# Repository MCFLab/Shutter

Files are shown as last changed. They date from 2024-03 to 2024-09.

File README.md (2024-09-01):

# Welcome to the Shutter Project!

The **Shutter Project** is an open-source development of a low-cost, general purpose shutter system based on ubiquitous actuators (servo motors or solenoids) that are connected to an Arduino-based controller. Several shutters can be controlled by one controller, reducing system cost. The state of the shutters can be controlled via a display built into the controller, by serial commands via USB, or by electrical control lines. The use of a microcontroller makes the shutter controller adaptable – only control options that are used need to be included, and the design accommodates a selection of display and actuator options. We provide designs for all required components, including 3D print files for the actuator holders and cases, software for the Arduino, libraries for serial communication (C and python), and example graphical user interfaces for testing. 

*Reference:*  Mathias S. Fischer and Martin C. Fischer. Cost-effective, open-source light shutters with Arduino control. [HardwareX 19, e00548 (2024)](https://doi.org/10.1016/j.ohx.2024.e00548)

## Rotary Solenoids
Since publication of the HardwareX paper, we have also tested the controller with rotary solenoids, which perform quite a bit better then servos. We added a document in the Docs folder describing the operation with rotary solenoids in a bit more detail. Also, for questions and discussion refer to the [this topic](https://forum.microlist.org/t/cost-effective-open-source-light-shutters-with-arduino-control/) in the [Builders/Tools Category](https://forum.microlist.org/c/builders-tools/21) of the [µForum](https://forum.microlist.org/).

## Contributing
I welcome your contributions with [pull-requests](https://github.com/MCFLab/Shutter/pulls) and [issues suggesting further improvement](https://github.com/MCFLab/Shutter/issues)!

## License
This work is licensed under the
[CERN Open Hardware Licence Version 2 - Weakly Reciprocal License](https://cern-ohl.web.cern.ch/).

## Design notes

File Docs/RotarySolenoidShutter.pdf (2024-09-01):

# Operation with a rotary solenoid

This document supplements the open-access paper Mathias S. Fischer and Martin C. Fischer, “Cost-effective, open-source light shutters with Arduino control,” HardwareX 19, e00548 (2024); https://doi.org/10.1016/j.ohx.2024.e00548

# Overview

Since publication of the HardwareX paper (https://doi.org/10.1016/j.ohx.2024.e00548) in June 2024 we have implemented shutters with rotary solenoids using the same Arduino controller.

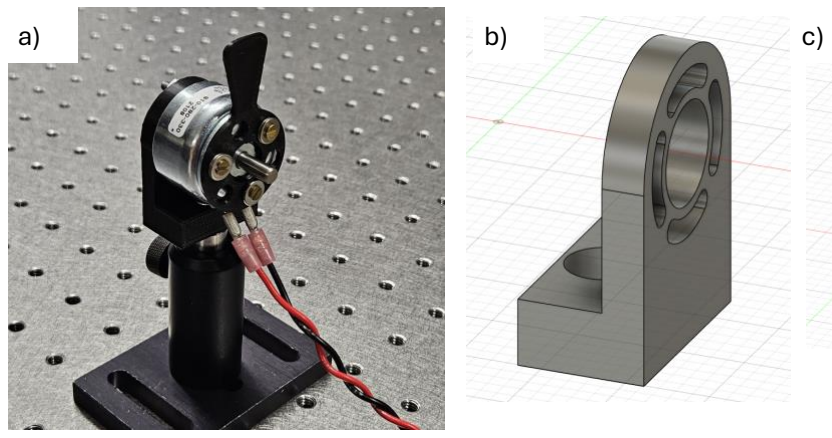
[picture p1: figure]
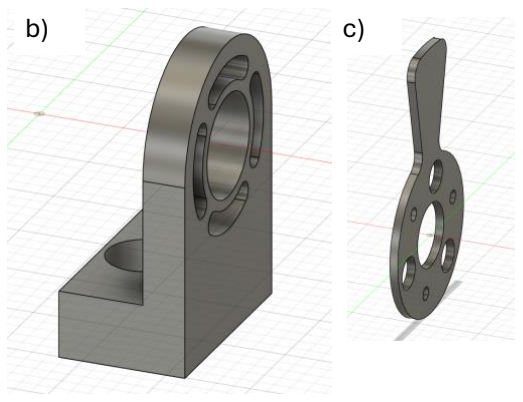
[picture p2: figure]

There are a wide range of rotary solenoids in production (see e.g. Ledex). (https://www.johnsonelectric.com/en/products/solenoids/rotary-solenoid) A few of them are available through distributors (e.g. Newark). (https://www.newark.com/b/ledex) The model we tested is a Ledex 810-280-330 (price at time of purchase ~$60). This particular model has a 25-degree stroke and can operate continuously with 12 V, provided by a power supply through the motor shield already used in our design. The solenoid rotates to the “open” position when energized and returns to the default “closed” position when no voltage is applied. Thus, this solenoid provides for a fail-safe shutter operation (it closes on power failure).

# Mechanical mounting

The shutter is mounted in a 3D printed holder with the threaded studs of the solenoid. The slots in the holder provide an adjustable mounting angle. A blade is attached to the rotatable plate of the solenoid with three mounting screws (in our case #3-48 screws). Please ensure that the screws do not extend through the top plate, otherwise they might impede the rotary motion (due to the ball race design, the front plate retracts during rotation). For testing purposes, we 3D-printed the blade, but for permanent operation a metal blade is preferred. The design for both the mount and blade can be found in the actuator mount directory of the Github repository. (https://github.com/MCFLab/Shutter/) Note that due to vibrations of the shutter during repeated opening and closing, the mounting nuts can loosen. Hence, lock washers or locknuts are recommended (or epoxy the nut).

Fig. 1: a) Picture of assembled rotary solenoid shutter, b) solenoid mount, and c) shutter blade.

# Electrical hookup

The electrical connection is identical to the case of the linear solenoid described in the HardwareX paper. The power supply voltage should be matched to the type (coil AWG) of the solenoid, but the motor shield limits supply voltage to 13.5V. For our solenoid, we used a supply voltage of 12 V.

# Operation

The operation of the rotary solenoid shutter is identical to the case with a linear solenoid. A “position” value of 0 means no voltage is applied (shutter closed), a position value of “255” means the full supply voltage is applied (shutter open). Note that in the open position, the solenoid draws the full current and can get warm.

# Performance

We measured the opening and closing times of the rotary solenoid shutter with a similar setup as described in the paper. Below are representative traces and average open/closing times and delays.

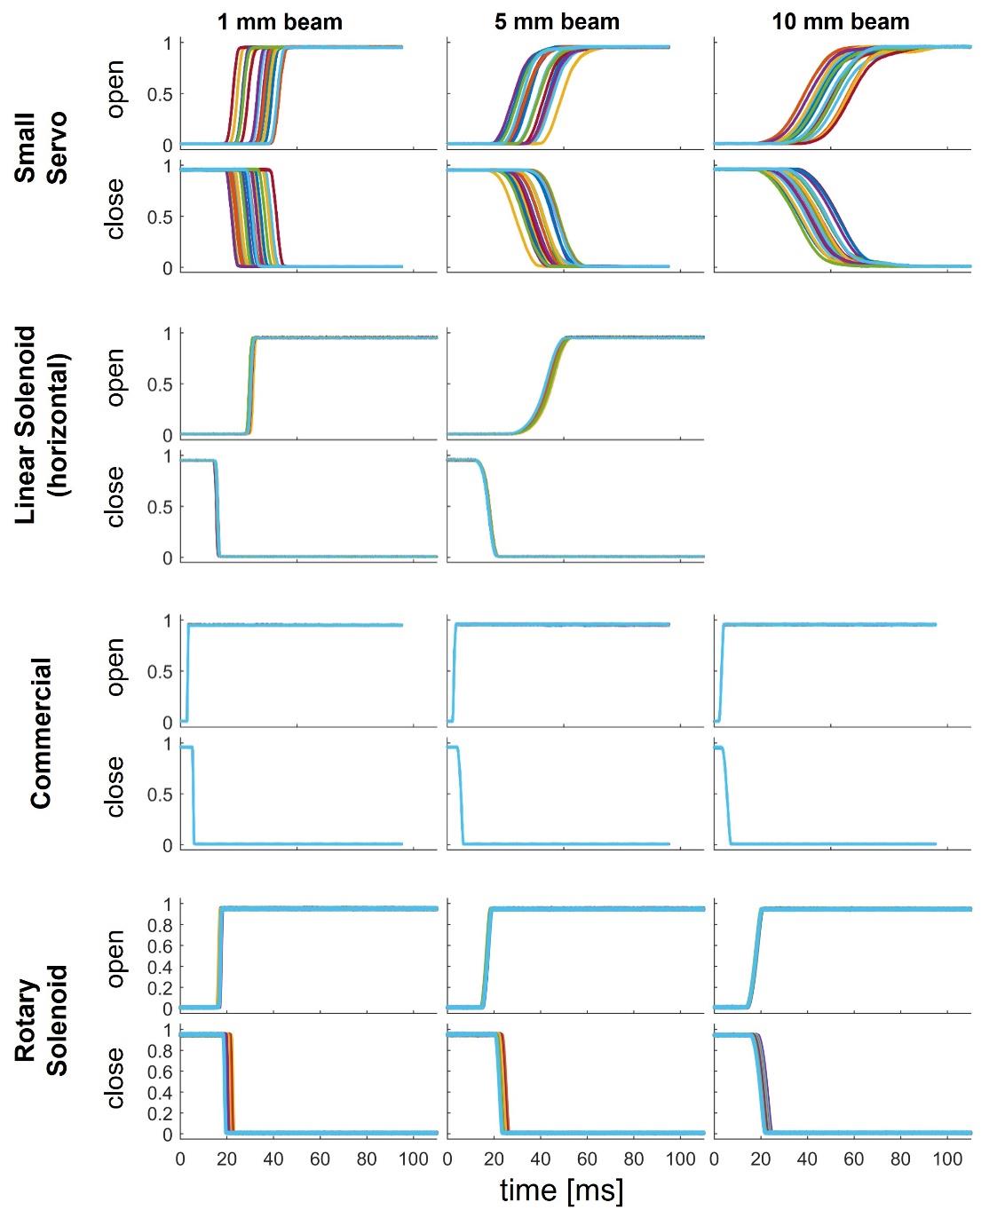
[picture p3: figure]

Fig. 2. Measured beam transmission during opening and closing of various shutters. The time t = 0 corresponds to the rising/falling edge of the digital control signal.

Table 1. Measured opening and closing times (τ) and delays (T).

Shutter type | Direc-tion | τ [ms] (∅1 mm) | T [ms] (∅1 mm) | τ [ms] (∅5 mm) | T [ms] (∅5 mm) | τ [ms] (∅10 mm) | T [ms] (∅10 mm)
Small Servo | open | 2.6 ± 0.19 | 32 ± 5.6 | 8.8 ± 0.44 | 39 ± 5.5 | 15 ± 0.63 | 48 ± 5.8
| close | 2.5 ± 0.12 | 30 ± 5.7 | 8.7 ± 0.33 | 40 ± 5.5 | 15 ± 0.36 | 45 ± 5.4
Solenoid (horizontal) | open | 3.5 ± 0.080 | 74 ± 3.2 | 20 ± 0.92 | 70 ± 2.5 | - | -
| close | 0.95 ± 0.003 | 16 ± 0.18 | 4.3 ± 0.015 | 15 ± 0.17 | - | -
Commer-cial | open | 0.20 ± 0.001 | 3.1 ± 0.004 | 0.63 ± 0.003 | 2.9 ± 0.005 | 0.94 ± 0.003 | 3.2 ± 0.006
| close | 0.30 ± 0.001 | 5.5 ± 0.006 | 1.2 ± 0.003 | 5.9 ± 0.002 | 1.7 ± 0.015 | 5.5 ± 0.013
Rotary Solenoid | open | 0.52 ± 0.01 | 17 ± 0.3 | 1.9 ± 0.02 | 17 ± 0.2 | 3.0 ± 0.04 | 18 ± 0.2
| close | 0.45 ± 0.01 | 20 ± 1.6 | 1.4 ± 0.01 | 22 ± 1.0 | 2.7 ± 0.01 | 20 ± 0.7

Not only are the opening/closing times of the rotary solenoid shutter shorter than the servo shutter and the linear solenoid shutter, but the timing is also more reproducible (the H-bridge on the motor shield is not limited by the PWM update rate (50 Hz) of the servo shield). Also, with a rotary solenoid a larger beam area can be achieved than with a linear solenoid (limited by the throw of the plunger).

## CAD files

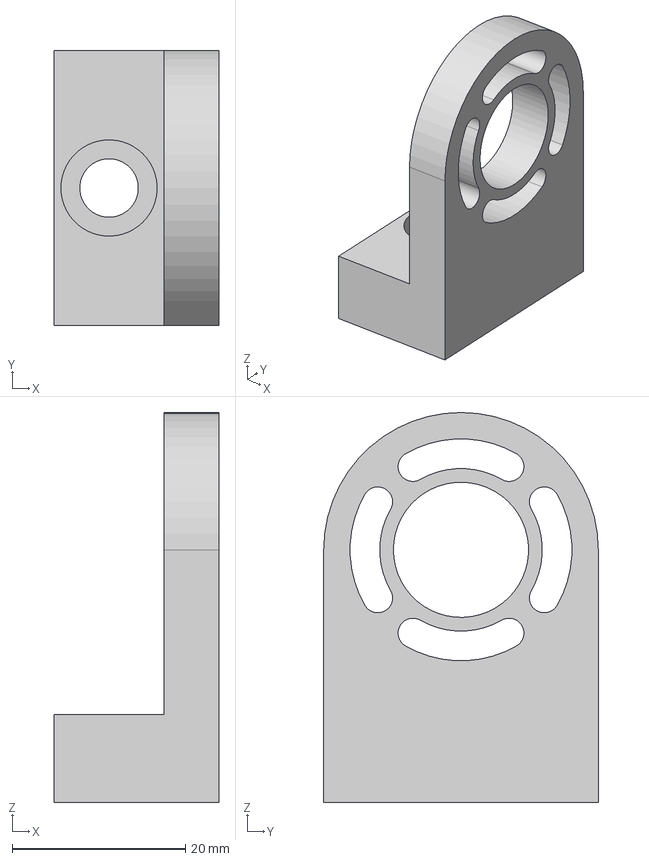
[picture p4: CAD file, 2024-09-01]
Actuator Mounts/RotationalSolenoidMount.step
19.1 x 31.8 x 45.1 mm

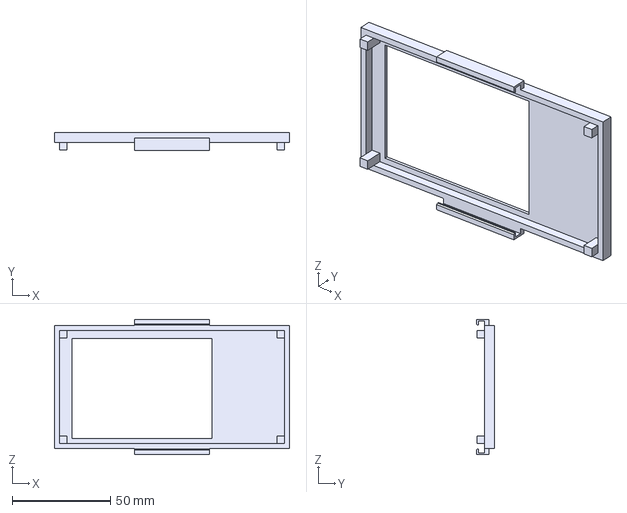
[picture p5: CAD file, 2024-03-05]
Enclosures/Lid_TFT.step
119.4 x 9.30 x 68.6 mm

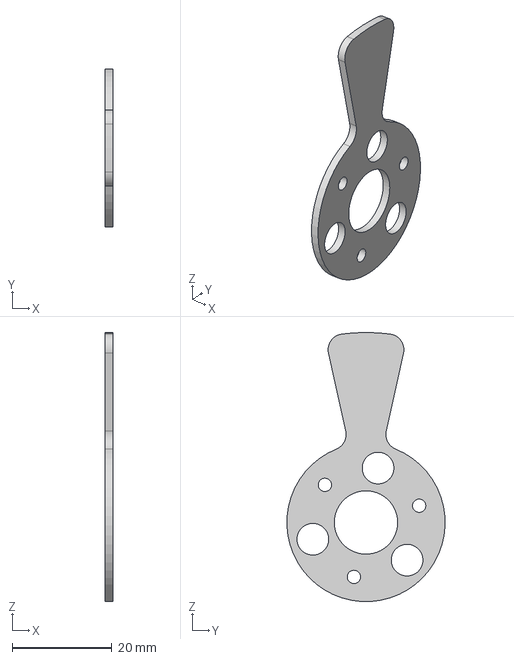
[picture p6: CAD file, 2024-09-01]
Actuator Mounts/RotationalSolenoidBlade.step
1.59 x 31.7 x 53.9 mm

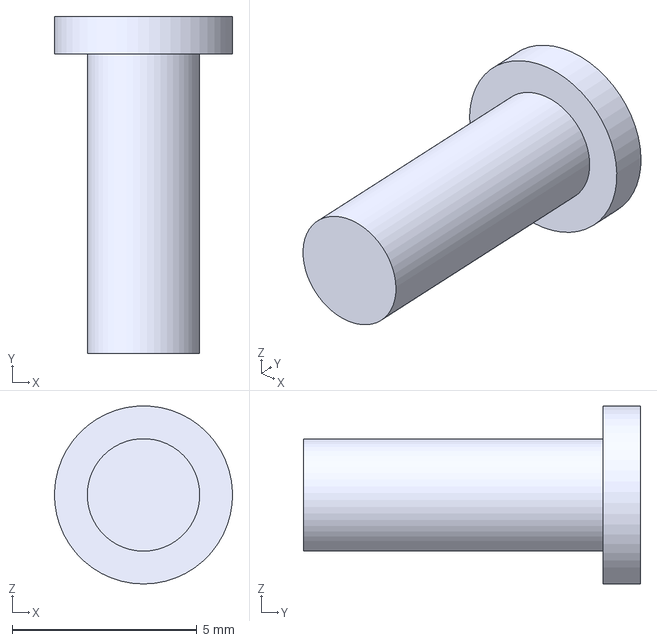
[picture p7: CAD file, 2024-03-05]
Enclosures/Button.step
4.82 x 9.14 x 4.82 mm

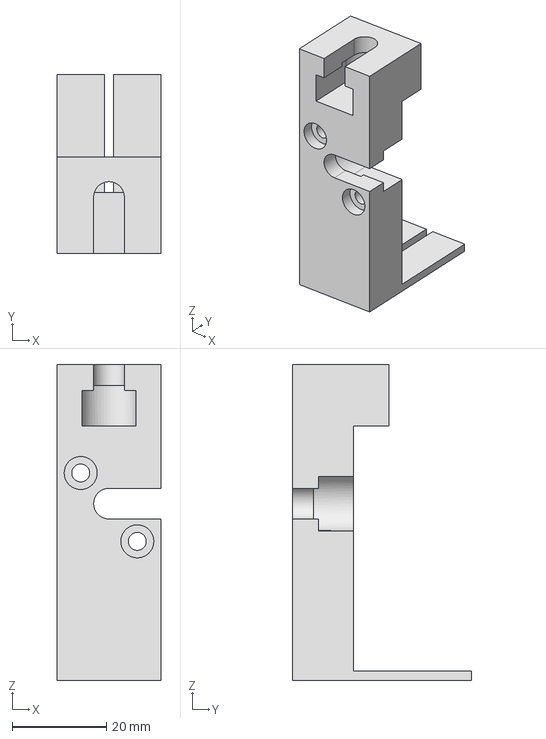
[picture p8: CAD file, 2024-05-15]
Actuator Mounts/SolenoidMount.step
22.0 x 38.0 x 67.0 mm

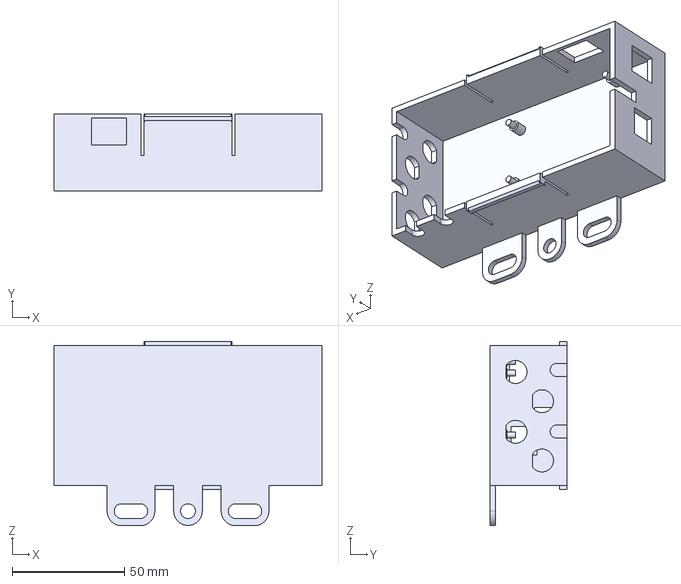
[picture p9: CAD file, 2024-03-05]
Enclosures/Shutter Case.step
119.4 x 34.3 x 82.2 mm

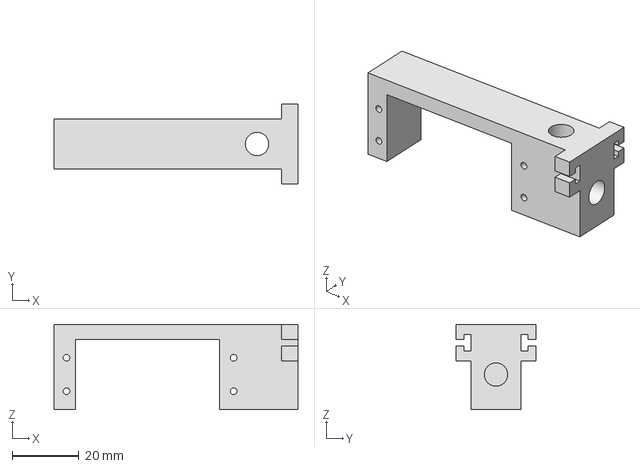
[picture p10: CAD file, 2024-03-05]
Actuator Mounts/ServoPostMount.step
73.0 x 24.0 x 25.5 mm

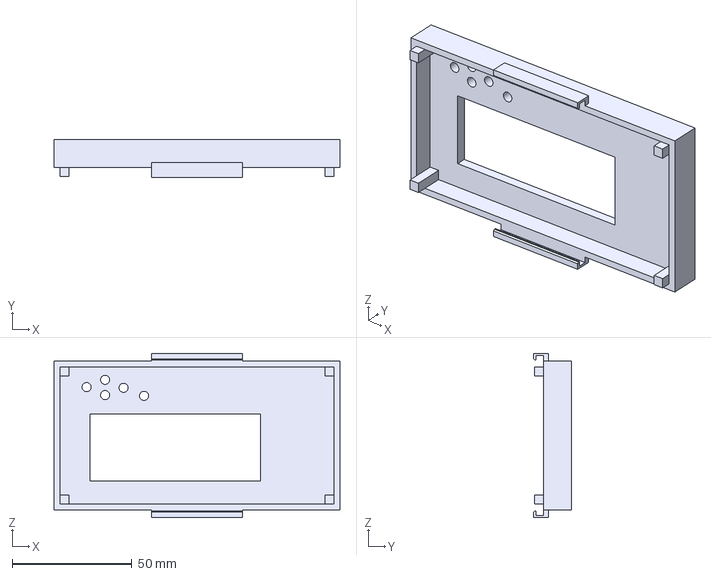
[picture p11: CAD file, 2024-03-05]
Enclosures/Lid_LCD.step
119.4 x 15.9 x 68.6 mm

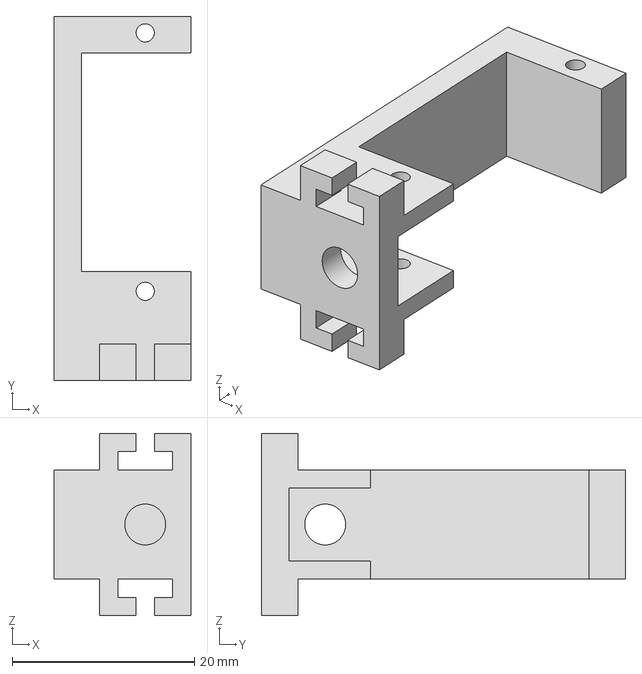
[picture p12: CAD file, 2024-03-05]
Actuator Mounts/ServoPostMount_Small.step
15.0 x 40.0 x 20.0 mm

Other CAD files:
Actuator Mounts/RotationalSolenoidBlade.stl
Actuator Mounts/RotationalSolenoidMount.stl
Actuator Mounts/ServoPostMount.stl
Actuator Mounts/ServoPostMount_Small.stl
Actuator Mounts/SolenoidMount.stl
Enclosures/Button.STL
Enclosures/Lid_LCD.STL
Enclosures/Lid_TFT.STL
Enclosures/Shutter Case.STL

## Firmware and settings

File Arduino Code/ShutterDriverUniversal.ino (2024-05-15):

///////////////////////////////////////////////////////////////////////
// Shutter driver sketch
// Martin Fischer, Duke University
// Written for the Arduino platform; controls actuators that serve as
//   shutters for some laser beams.
// Uses the Adafruit TFT Touch Shield or the Adafruit LCD dislay
// Also uses the Adafruit PWM shield or motor shield
///////////////////////////////////////////////////////////////////////

////////////////////////////
// for memory diagnostics
//extern char *__brkval;
////////////////////////////

#include "Common.h"
#include "Parameters.h"
#include "RCServo.h"
#include "Solenoid.h"
#include "TFT.h"
#include "LCD.h"
#include "SerialComm.h"
#include "DigInput.h"

#define SERIAL_DEBUG  0

//************************************************
// global variables
//************************************************
Parameters _params = Parameters();
#ifdef SHUTTER_RCSERVO
RCServo _shutter = RCServo();
#endif
#ifdef SHUTTER_SOLENOID
Solenoid _shutter = Solenoid();
#endif
#ifdef DISPLAY_TFT
TFT _display = TFT();
#endif
#ifdef DISPLAY_LCD
LCD _display = LCD();
#endif
#ifdef SERIALCOMM
SerialComm _serComm = SerialComm();
#endif
#ifdef DIGINPUT
DigInput _digInput = DigInput();
#endif

static unsigned long _lastStateChangeTime_ms = 0;
static int8_t _devState[MAXSHUTTERS];


//************************************************
// functions for debugging
//************************************************
////////////////////////////
// create dummy values for the shutter parameters
////////////////////////////
void createDummyParameters(void)
{
  // default solenoid parameters
  // _params.set(-1, 0, -1, 255, 0, 500, "Label0");
  // _params.set(-1, 1, -1, 255, 0, 500, "Label1");
  // _params.set(-1, 2, -1, 255, 0, 500, "Label2");
  // _params.set(-1, 3, -1, 255, 0, 500, "Label3");

  // default servo parameters
  // _params.set(-1, 0, -1, 200, 300, 500, "Label0");
  // _params.set(-1, 1, -1, 200, 300, 500, "Label1");
  // _params.set(-1, 2, -1, 200, 300, 500, "Label2");
  // _params.set(-1, 3, -1, 200, 300, 500, "Label3");
}


//************************************************
// setup
//************************************************
void setup() {

  // initialize the array to an unused state
  for(uint8_t ind = 0; ind < sizeof(_devState); ++ind) _devState[ind] = -2;

#ifdef SERIALCOMM
  _serComm.Begin(&_params, _devState); // default timeout
#endif

  _shutter.Begin();

  // read parameter info from EEPROM
  _params.readFromEEPROM();

  // in case of erroneous behavior when first using the Arduino, it could be becasue of some strange
  // values in the EEPROM. To rule that out, comment out the above line and instead use the two lines
  // below. These save some pre-defined values into the EEPROM. Then revert back to the original
  //  config and compile/download the code again.
//  createDummyParameters();
//  _params.saveToEEPROM();

  // set up the display
#if defined DISPLAY_TFT || defined DISPLAY_LCD
  _display.Begin();
  updateDisplayInfo();
#endif

// set up the digital inputs
#ifdef DIGINPUT
  _digInput.Begin();
#endif

}


//************************************************
// loop
//************************************************
void loop() {

#if defined DISPLAY_TFT || defined DISPLAY_LCD
  checkDisplayInput();
#endif
#ifdef SERIALCOMM
  checkSerialInput();
#endif
#ifdef DIGINPUT
  checkDigitalInput();
#endif
  checkForIdle(); // disconnects the servo after a while of inactivity

}


//************************************************
// action functions
//************************************************
////////////////////////////
// check for display input
////////////////////////////
#if defined DISPLAY_TFT || defined DISPLAY_LCD
void checkDisplayInput(void)
{
   int8_t device;
   int8_t desiredState;

  if (_display.CheckInput(&device, &desiredState)) {
    updateState(device, desiredState);
  }
}
#endif

////////////////////////////
// check for serial input
////////////////////////////
#ifdef SERIALCOMM
void checkSerialInput(void)
{
  SerialActionType action;
  int8_t device;
  int8_t desiredState;
  uint16_t manualPos;

  _serComm.CheckAction(&action, &device, &desiredState, &manualPos);
  if (action == None)
    return;
  else if (action == ParamChange){
#if defined DISPLAY_TFT || defined DISPLAY_LCD
    updateDisplayInfo();
#endif
  } else if (action == StateChange)
    updateState(device, desiredState);
  else if (action == ManualPos) {
    _shutter.SetShutterValue(_params.shieldChannel(device), manualPos);
    _lastStateChangeTime_ms = millis();
    _devState[device]=2; // flag for manual set
  }

}
#endif

////////////////////////////
// check for digital input
////////////////////////////
#ifdef DIGINPUT
void checkDigitalInput(void)
{

  uint8_t portState; // byte that defines the bits in the input port (only 0-3 are used)
  int8_t digInput; // input number for the device (0-3)
  int8_t newState; // desired state of the device

  if (_digInput.CheckState(&portState))
  {
    // loop through devices
    for (int8_t dev=0; dev<_params.numShutters(); dev++) {
      digInput = _params.digInput(dev); 
      if (digInput==-1) continue; // no digital input defined for this device
      newState = ( (portState & bit(digInput)) > 0 ? 1 : 0);
      if (_devState[dev] != newState ) {
        updateState(dev, newState);
#if SERIAL_DEBUG>0
        Serial.print(F("digInput = ")); Serial.println(digInput);
        Serial.print(F("portstate = ")); Serial.println(portState);
        Serial.print(F("Dig update device ")); Serial.print(dev); Serial.print(F(" to ")); Serial.print(newState); Serial.println("");
#endif      
      }
    }
  }

}
#endif

////////////////////////////
// check for elapsed time to disable the servos
////////////////////////////
void checkForIdle(void)
{
  unsigned long currentTime;
  currentTime = millis();

  if ( IDLEINTERVAL_S > 0 
          && currentTime - _lastStateChangeTime_ms > 1000*(unsigned long)IDLEINTERVAL_S) {
    for (int8_t dev=0; dev<_params.numShutters(); dev++) {
      if (_devState[dev]==-1) continue; // already disabled
      updateState(dev, -1);
#if SERIAL_DEBUG>0
      Serial.print(F("Setting device ")); Serial.print(dev); Serial.println(" to idle.");
#endif      
      _shutter.SetShutterValue(_params.shieldChannel(dev), 0);
      _devState[dev]=-1;
    }
  }
}


//************************************************
// Utility functions
//************************************************
/////////////////////////////
// memory diagnostics
//Serial.print(F("Free memory: ")); Serial.println(freeMemory());
////////////////////////////
// set the shutters
////////////////////////////
void updateState(int8_t device, int8_t state)
{
  // only update shutter state if needed
  if (state==_devState[device]) return;

  if (state==0) { // close
    _shutter.SetShutterValue(_params.shieldChannel(device), _params.posClosed(device));
  } else if (state==1) { // open
    _shutter.SetShutterValue(_params.shieldChannel(device), _params.posOpen(device));
  } else if (state==-1) { // idle
    _shutter.SetShutterValue(_params.shieldChannel(device), 0);
  }
  _devState[device]=state;
#if defined DISPLAY_TFT || defined DISPLAY_LCD
  _display.ChangeDevState(device, state);
#endif
  _lastStateChangeTime_ms = millis();
}

////////////////////////////
// update the display
////////////////////////////
#if defined DISPLAY_TFT || defined DISPLAY_LCD
void updateDisplayInfo(void)
{
  char label[MAXLABELCHARS+1];
  int8_t numShutters = _params.numShutters();
  _display.SetNumDevs(numShutters);

  for (int8_t z = 0; z<numShutters; z++) {
    _params.getPrintLabel(z, label);
    _display.SetDevText(z, label);
  }
  _display.RefreshDisplay();
}
#endif

//////////////////////////
// memory diagnostics
// int freeMemory(void)
// {
//   char top;
//   return &top - __brkval;
// }

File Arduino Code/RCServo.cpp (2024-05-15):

#include "Common.h"
// only include if SHUTTER_RCSERVO is chosen in "Common.h"
#ifdef SHUTTER_RCSERVO


#include <Arduino.h>
#include <Wire.h>
#include <Adafruit_PWMServoDriver.h>
#include "RCServo.h"

#define SERIAL_DEBUG  0


// *************************************************************************************
// defines
// *************************************************************************************

// *************************************************************************************
// global variables
// *************************************************************************************
Adafruit_PWMServoDriver _pwm = Adafruit_PWMServoDriver(RCSERVO_BOARDID);


// *************************************************************************************
// RCServo class
// *************************************************************************************
////////////////////////////
// Constructor
RCServo::RCServo()
{
}

////////////////////////////
// Initialize stuff
RCServo::Begin()
{
#if SERIAL_DEBUG>0
  Serial.println(F("RCServo Begin."));
#endif      

  // set up PWM chip 
  _pwm.begin();
  _pwm.setOscillatorFrequency(25000000);  // Reference frequency of the PWM chip
  _pwm.setPWMFreq(RCSERVO_FREQ);

}

////////////////////////////
// Action functions
RCServo::SetShutterValue(uint8_t dev, uint16_t value)
{
  _pwm.setPWM(dev, 0, value);
#if defined SERIALCOMM && SERIAL_DEBUG>0
  Serial.print(F("Setting PWM ")); Serial.print(dev); Serial.print(" to ");
  Serial.print(0); Serial.print("/"); Serial.print(value); Serial.println(".");
#endif      
}

#endif // SHUTTER_RCSERVO

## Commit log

2024-05-15 Update to include solenoid as an actuator option
    [ServoPostMount.step, ServoPostMount.stl, ServoPostMount_Small.step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]
2024-09-01 Adding rotary solenoids to the list of actuators
    [RotationalSolenoidBlade.step, RotationalSolenoidBlade.stl, RotationalSolenoidMount.step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]
